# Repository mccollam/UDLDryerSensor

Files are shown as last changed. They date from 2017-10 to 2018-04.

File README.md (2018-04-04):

Dryer Sensor
============

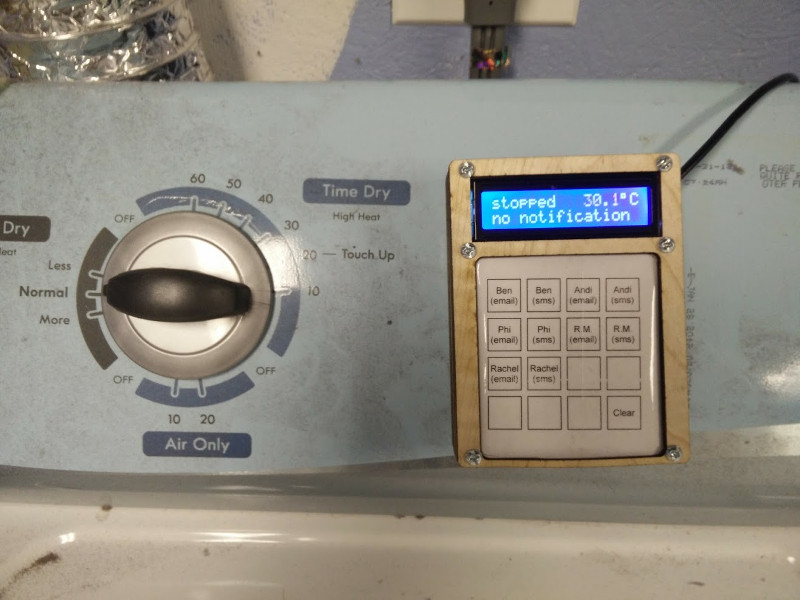
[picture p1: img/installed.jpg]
Dryer Sensor installed and running


This is a simple ESP8266-based sensor to detect when a clothes dryer has
stopped and send a message to an MQTT server.  The MQTT server can then
send a notification as appropriate (e.g. SMS, email, etc.)

(Note that the MQTT server is not part of this project but is separate.
This project does not directly notify anyone, merely inform the MQTT server
when the dryer changes state and what the new state is, or when the
keypad is used to change the person and method to notify.)

The sensor is built from the following:

* Wemos D1 Mini ESP8266
* HD44780 2-line LCD character display
* MPU6050 accelerometer
* 4x4 matrix keypad, exposed via I2C

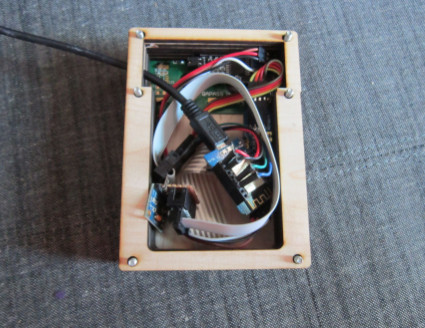
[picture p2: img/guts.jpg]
Internals of the unit


Some sketches for cases are available in the `cases` directory in
[OpenSCAD](http://www.openscad.org/) format.  The 3D cases can be used for
3D printing, while the 2D cases can be laser cut from thin pieces of wood
or similar.  (You may need to modify the cases a bit depending on the sizes
of the components used.)

Notifications are provided by a daemon (under "notifier") that listens for
MQTT messages and sends the relevant information to an external notification
system.  Currently [Twilio](https://www.twilio.com) and
[Amazon SNS](https://aws.amazon.com/sns/) are supported but this could easily
be extended to others.

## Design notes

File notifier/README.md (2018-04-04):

# Notification daemon for dryer sensor

This should be run on a server somewhere in the same network as the dryer
sensor.  It will listen for MQTT messages and notify people as appropriate.

This uses [Twilio](https://www.twilio.com) for SMS notification and
[AWS SNS](https://aws.amazon.com/sns/) for email notification.  SNS can also
do SMS notification but requires much more configuration than Twilio and so
is out of scope for this.  (It requires setup for email as well which is
also out of scope, but I am using it myself so leaving it in as a reference.
You could always use another email notifcation service instead.)  SNS
requires a schema to be defined on the backend that matches what is provided
in this file.

To use, configure the Twilio information and/or the SNS URL at the top of
the file and run!

## Caveats:

Sending an SMS notification to a user not defined in the list of phone
numbers will cause a traceback.  This could easily be caught but I am
lazy and have a limited number of users to notify so it was easy to make
sure everything worked for my purposes :)

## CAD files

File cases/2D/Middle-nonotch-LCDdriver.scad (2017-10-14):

$fn=64;
difference() {
    roundedsquare(119, 88, 3);
    
    // LCD cutout:
    translate([7, 8])
        square([25, 72]);
    
    // LCD driver notch:
    translate([2, 33])
        square([5, 47]);
    
    // Screw holes (LCD):
    translate([4.5, 6.5])
        circle(r=2);
    translate([4.5, 81.5])
        circle(r=2);
    translate([35.5, 6.5])
        circle(r=2);
    translate([35.5, 81.5])
        circle(r=2);
    
    // Screw holes (bottom):
    translate([114.5, 6.5])
        circle(r=2);
    translate([114.5, 81.5])
        circle(r=2);
        
    // Electronics space
    translate([28, 13])
        roundedsquare(82, 62, 3);
        
}

module roundedsquare(xdim, ydim, rdim) {
    $fn=64;
    hull() {
        translate([rdim, rdim, 0])
            circle(r=rdim);
        translate([xdim-rdim, rdim, 0])
            circle(r=rdim);
        translate([rdim, ydim-rdim, 0])
            circle(r=rdim);
        translate([xdim-rdim, ydim-rdim, 0])
            circle(r=rdim);
    }
}

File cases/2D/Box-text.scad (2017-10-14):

$fn=64;
union() {
    difference() {
        // Box:
        roundedcube(119, 88, 24, 3);
        translate([2, 2, 4])
            cube([115, 84, 28]);
        
        // LCD cutout:
        translate([7, 8, -2])
            cube([25, 72, 7]);
        // LCD circuit notch:
        translate([13, 4.5, 1])
            cube([12, 4.5, 7]);
        
        // USB power cable cutout:
        translate([-1, 14, 20])
            rotate([0, 90, 0])
                roundedcube(6, 10, 5, 1);
        
        // Screw holes (LCD):
        translate([4.5, 6.5, -1])
            cylinder(h=6, r=2);
        translate([4.5, 81.5, -1])
            cylinder(h=6, r=2);
        translate([35.5, 6.5, -1])
            cylinder(h=6, r=2);
        translate([35.5, 81.5, -1])
            cylinder(h=6, r=2);
        
        // Screw holes (bottom):
        translate([114.5, 6.5, -1])
            cylinder(h=6, r=2);
        translate([114.5, 81.5, -1])
            cylinder(h=6, r=2);
        
        // Screw head sinks (LCD):
        translate([4.5, 6.5, -1])
            cylinder(h=3, r=2.5);
        translate([4.5, 81.5, -1])
            cylinder(h=3, r=2.5);
        translate([36.5, 6.5, -1])
            cylinder(h=3, r=2.5);
        translate([36.5, 81.5, -1])
            cylinder(h=3, r=2.5);
        // Screw head sinks (bottom):
        translate([114.5, 6.5, -1])
            cylinder(h=3, r=2.5);
        translate([114.5, 81.5, -1])
            cylinder(h=3, r=2.5);

        // Keypad space
        translate([38, 9, -1])
            roundedcube(78, 70, 2, 3);
        
        // Keypad cable cutout
        translate([111, 33, -1])
            cube([3, 22, 7]);
            
        // Text
        linear_extrude(.5)
            translate([5, 70, -1])
                rotate([0, 180, 90])
                    text("UDL Dryer 2.0", font="Existence", size=3);
    }
 
    // LCD support post
    translate([13,80,4])
        cube([12, 7, 3]);

}

module roundedcube(xdim, ydim, zdim, rdim) {
    $fn=64;
    hull() {
        translate([rdim, rdim, 0])
            cylinder(r=rdim, h=zdim);
        translate([xdim-rdim, rdim, 0])
            cylinder(r=rdim, h=zdim);
        translate([rdim, ydim-rdim, 0])
            cylinder(r=rdim, h=zdim);
        translate([xdim-rdim, ydim-rdim, 0])
            cylinder(r=rdim, h=zdim);
    }
}

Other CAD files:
cases/2D/Back.scad
cases/2D/Face.scad
cases/2D/Layer2.scad
cases/2D/Middle-nonotch.scad
cases/2D/Middle-notch.scad
cases/2D/Middle-strut.scad
cases/3D/Back.scad
cases/3D/Box-thick.scad

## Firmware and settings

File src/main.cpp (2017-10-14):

// Uncomment to update with resin.io:
//#define RESIN_IO
// Set to resin.io dependent app ID (if using resin.io):
#define RESIN_APPLICATION "12345"

// ESP8266 WiFi support:
#include <ESP8266WiFi.h>

// I2C support:
#include <Wire.h>

// LCD support:
#include <hd44780.h>
#include <hd44780ioClass/hd44780_I2Cexp.h> // i2c expander i/o class header

// Matrix keypad support:
#include <Keypad_I2C/Keypad_I2C.h>
#include <Keypad.h>

// MQTT support:
#include <PubSubClient.h>

// Accelerometer support:
#include <MPU6050.h>

// Resin.io support:
#ifdef RESIN_IO
#include <resin.h>
Resin resin;
#endif /* RESIN_IO */

/*** WiFi setup ***/
const char* ssid = "YOUR_SSID_HERE";
const char* password = "YOUR_PASSWORD_HERE";

WiFiClient wifiClient;

/*** MQTT setup ***/
const char* mqtt_server = "mqtt.YOUR_MQTT.com";
PubSubClient mqtt(wifiClient);
char msg[50];
const char mqttTopicPerson[] = "udl/basement/dryer/notifyPerson";
const char mqttTopicMethod[] = "udl/basement/dryer/notifyMethod";
const char mqttTopicStatus[] = "udl/basement/dryer/status";
const unsigned int maxPersonLength = 20;
const unsigned int maxMethodLength = 10;
char notifyPerson[maxPersonLength] = "";
char notifyMethod[maxMethodLength] = "";

/*** Keypad setup ***/
#define KEYPAD_ADDR 0x38

const byte ROWS = 4;
const byte COLS = 4;
char keys[ROWS][COLS] = {
  {'1','2','3', 'A'},
  {'4','5','6', 'B'},
  {'7','8','9', 'C'},
  {'*','0','#', 'D'}
};
byte rowPins[ROWS] = {0, 1, 2, 3};
byte colPins[COLS] = {4, 5, 6, 7};

Keypad_I2C keypad = Keypad_I2C( makeKeymap(keys), rowPins, colPins, ROWS, COLS, KEYPAD_ADDR );


/*** LCD setup ***/
const int LCD_ROWS = 2;
const int LCD_COLS = 16;
hd44780_I2Cexp lcd(0x3f);


/*** Accelerometer setup ***/
MPU6050 mpu;
// Minimum delta(accel) to count as motion:
#define JITTER 500
// Number of sequential running/stopped measurements to change state:
#define STATELIMIT 20
// When to throw out measurements and start fresh:
#define CLEARLIMIT 144000
int16_t lastX, lastY, lastZ;
unsigned int runCtr, stopCtr;
bool lastRunning;
bool dryerRunning;

/*** Function Definitions ***/

void mqtt_reconnect();
void wifi_reconnect();
void set_notify(const char*, const char*);
void set_notify_mqtt();
void set_status_mqtt();
void set_notify_lcd();
void set_status_lcd();
void keypadEvent(KeypadEvent);
void mqtt_received(char*, byte*, unsigned int);
void notify();


void setup()
{
  Serial.begin(115200);
  Serial.println("Starting setup");

  // Init LCD
  if (lcd.begin(LCD_COLS, LCD_ROWS))
    Serial.println("ERROR IN lcd.begin()");
  Serial.print("LCD address: ");
  Serial.println(lcd.getProp(hd44780_I2Cexp::Prop_addr));

  // Init WiFi
  wifi_reconnect();

  // Init keypad
  keypad.begin();
  keypad.addEventListener(keypadEvent);
  Serial.println("Keypad configured");

  // Init MQTT
  mqtt.setServer(mqtt_server, 1883);
  mqtt.setCallback(mqtt_received);

  // Init accelerometer
  //Wire.begin(); // already handled by LCD?
  Serial.print("Initializing accelerometer...");
  mpu.initialize();
  if (mpu.testConnection())
    Serial.println(" done.");
  else
  {
    Serial.println(" failed!  Dying...");
    lcd.setCursor(0, 1);
    lcd.print("NO ACCELEROMETER");
    while (true); // just die here
  }
  lastX = lastY = lastZ = 0;
  runCtr = stopCtr = 0;
  lastRunning = false;
  dryerRunning = false;

  #ifdef RESIN_IO
    // Init resin.io integration
    resin.Setup(RESIN_APPLICATION, ssid, password, false);
  #endif /* RESIN_IO */

  Serial.println("Ready.");
}

void loop()
{
  int16_t aX, aY, aZ, dX, dY, dZ;
  // Make sure we are connected
  if (WiFi.status() != WL_CONNECTED)
  {
    wifi_reconnect();
    set_notify_lcd();
  }
  if (!mqtt.connected())
  {
    mqtt_reconnect();
    set_notify_lcd();
  }

  // Service MQTT client
  mqtt.loop();

  // Service accel
  mpu.getAcceleration(&aX, &aY, &aZ);

  dX = abs(aX - lastX);
  dY = abs(aY - lastY);
  dZ = abs(aZ - lastZ);

  lastX = aX;
  lastY = aY;
  lastZ = aZ;

  /*
  Serial.print("aX: "); Serial.print(aX);
  Serial.print(" aY: "); Serial.print(aY);
  Serial.print(" aZ: "); Serial.println(aZ);
  Serial.print("dX: "); Serial.print(dX);
  Serial.print(" dY: "); Serial.print(dY);
  Serial.print(" dZ: "); Serial.println(dZ);
  */

  if ( (dX > JITTER) || (dY > JITTER) || (dZ > JITTER) )
  {
    if (lastRunning)
      runCtr++;
    else
    {
      stopCtr = 0;
      lastRunning = true;
    }
  }
  else
  {
    if (lastRunning)
    {
      lastRunning = false;
      runCtr = 0;
    }
    else
      stopCtr++;
  }

  if ( (runCtr > STATELIMIT) && (!dryerRunning) )
  {
    dryerRunning = true;
    set_status_mqtt();
    stopCtr = 0;
  }
  else if ( (stopCtr > STATELIMIT) && (dryerRunning) )
  {
    dryerRunning = false;
    set_status_mqtt();
    runCtr = 0;
  }

  if ( (runCtr > CLEARLIMIT) || (stopCtr > CLEARLIMIT) )
  {
      runCtr = 0;
      stopCtr = 0;
  }

  // Update LCD
  set_status_lcd();

  // Not sure why I  need to actively look for keypad events here; they are on a callback
  KeypadEvent key = keypad.getKey();
  if (key)
    Serial.println(key);

  #ifdef RESIN_IO
    // Check for application updates
    resin.Loop();
  #endif /* RESIN_IO */

  delay(100);
}

void keypadEvent(KeypadEvent key)
{
  // String literals in code are apparently of type String rather than const char[] :(
  const char* pBen = "Ben";
  const char* pPhi = "Phi";
  const char* pRachel = "Rachel";
  const char* pAndi = "Andi";
  const char* pRM = "R.M.";
  const char* mEmail = "email";
  const char* mSMS = "sms";
  const char* blank = "";

  Serial.print("Keypad event: ");
  Serial.println(key);

  if (keypad.getState() == PRESSED)
  {
    switch (key)
    {
      case '1': // Ben email
        set_notify(pBen, mEmail);
        break;
      case '2': // Ben sms
        set_notify(pBen, mSMS);
        break;
      case '4': // Phi email
        set_notify(pPhi, mEmail);
        break;
      case '5': // Phi sms
        set_notify(pPhi, mSMS);
        break;
      case '7': // Rachel email
        set_notify(pRachel, mEmail);
        break;
      case '8': // Rachel sms
        set_notify(pRachel, mSMS);
        break;
      case '3': // Andi email
        set_notify(pAndi, mEmail);
        break;
      case 'A': // Andi sms
        set_notify(pAndi, mSMS);
        break;
      case '6': // R.M. email
        set_notify(pRM, mEmail);
        break;
      case 'B': // R.M. sms
        set_notify(pRM, mSMS);
        break;
      default:  // clear
        set_notify(blank, blank);
        break;
    }
  }
}

void set_notify(const char* person, const char* method)
{
  // Called when the person/method is updated via keypad
  // Convenience function to update the LCD as well as send out
  // an MQTT blast

  Serial.print("Set notification: ");
  Serial.print(person);
  Serial.print(" - ");
  Serial.println(method);

  // Update the notification details
  strcpy(notifyPerson, person);
  strcpy(notifyMethod, method);

  // Update the LCD and the MQTT server
  set_notify_lcd();
  set_notify_mqtt();
}

void set_notify_lcd()
{
  // Update LCD
  lcd.setCursor(0, 1);
  lcd.print("                ");
  lcd.setCursor(0, 1);
  if (strlen(notifyPerson) > 1)
  {
    lcd.print(notifyPerson);
    lcd.print(" [");
    lcd.print(notifyMethod);
    lcd.print("]");
  }
  else
  {
    lcd.print("no notification");
  }
}

void set_status_lcd()
{
    lcd.setCursor(0, 0);
    lcd.print(dryerRunning ? "running" : "stopped");
    lcd.print("   ");
    // Calculation for real temperature from https://www.i2cdevlib.com/forums/topic/53-mpu-6050-temperature-compensation/
    String temp = String(round((mpu.getTemperature()/340. + 36.53) * 10) / 10.0).substring(0, 4);
    lcd.print(temp + (char)223 + "C"); // 223 == degree sign ⁰
}

void set_notify_mqtt()
{
  // Publish MQTT message
  mqtt.publish(mqttTopicPerson, notifyPerson, true);
  mqtt.publish(mqttTopicMethod, notifyMethod, true);
}

void set_status_mqtt()
{
    mqtt.publish(mqttTopicStatus, dryerRunning ? "running" : "stopped", true);
}


void mqtt_received(char* topic, byte* payload, unsigned int length)
{
  // Callback for dealing with MQTT messages received

  // Note that MQTT payloads are *not* null-terminated.  So we'll track
  // through them one byte at a time to do a cheap knock-off of strcpy()
  // and then either add a null terminator (if there's space) or just
  // truncate the last character and replace it with the null terminator
  // (if the string has filled up the array).  What a world, what a world.
  int i;
  
  Serial.print("MQTT message received: [");
  Serial.print(topic);
  Serial.print("] - [");

  // Boy a switch() would be nice here :(
  if (strcmp(topic, mqttTopicPerson) == 0)
  {
    for (i = 0; i < length && i < maxPersonLength; i++)
    {
      notifyPerson[i] = (char)payload[i];
      Serial.print(notifyPerson[i]);
    }
    if (i < maxPersonLength)
      i++;
    notifyPerson[i] = '\0';
  }

  if (strcmp(topic, mqttTopicMethod) == 0)
  {
    for (i = 0; i < length && i < maxMethodLength; i++)
    {
      notifyMethod[i] = (char)payload[i];
      Serial.print(notifyMethod[i]);
    }
    if (i < maxMethodLength)
      i++;
    notifyMethod[i] = '\0';
  }

  Serial.println("]");

  // We just received this via MQTT, so only update the LCD:
  set_notify_lcd();

}

void mqtt_reconnect()
{
  // Keep reconnecting to the MQTT server until we get there
  // (This is intentionally blocking!)
  
  while (!mqtt.connected()) {
    Serial.print("Connecting to MQTT server...");
    lcd.setCursor(0, 0);
    lcd.print("MQTT connect:");
    lcd.setCursor(0, 1);
    lcd.print(mqtt_server);

    if (mqtt.connect("UDL Dryer"))
    {
      Serial.println(" connected.");
      mqtt.subscribe(mqttTopicPerson);
      mqtt.subscribe(mqttTopicMethod);
    }
    else
    {
      Serial.print(" failed; rc=");
      Serial.println(mqtt.state());
      Serial.println("Waiting to retry...");
      delay(5000);
    }
  }
}

void wifi_reconnect()
{
  Serial.print("Connecting to WiFi AP ");
  Serial.println(ssid);
  lcd.setCursor(0, 0);
  lcd.print("WiFi Connect:");
  lcd.setCursor(0, 1);
  lcd.print(ssid);

  WiFi.begin(ssid, password);
  while (WiFi.status() != WL_CONNECTED)
  {
    delay(500);
    Serial.print(".");
  }

  Serial.println("");
  Serial.print("Connected.  IP address: ");
  Serial.println(WiFi.localIP());

}
